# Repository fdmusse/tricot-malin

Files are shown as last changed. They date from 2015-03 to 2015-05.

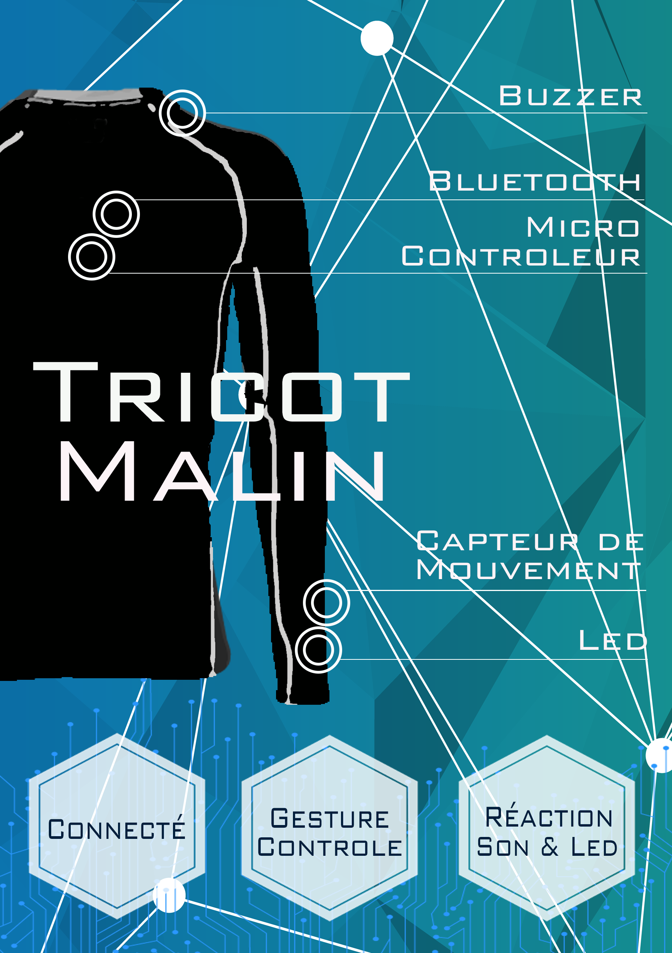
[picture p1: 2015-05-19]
img/flyerPoster/Poster.png

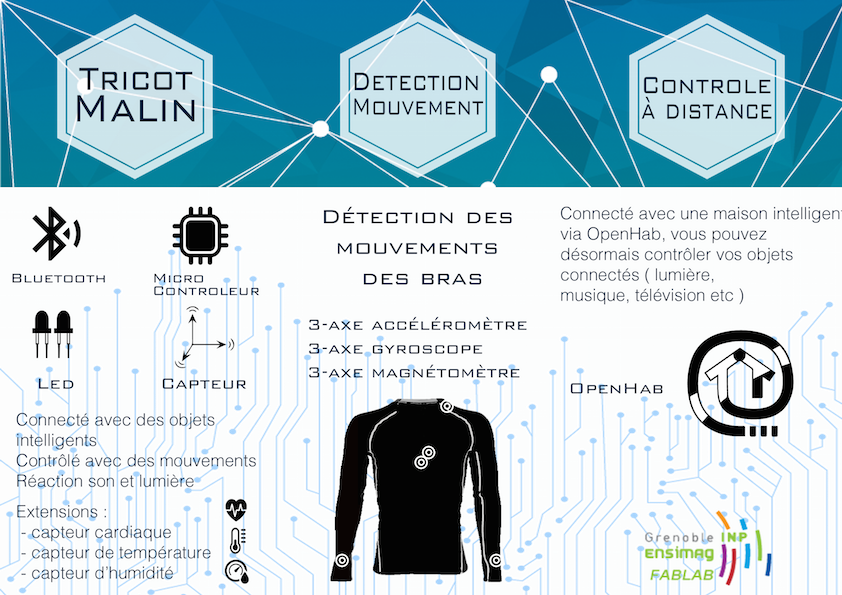
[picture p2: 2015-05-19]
img/flyerPoster/Flyer.png

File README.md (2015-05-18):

# tricot-malin

Tricot Malin (smart sweater in French) is a smart t-shirt that makes it possible to interact with the digital environment that surround us through the use of simple gestures.

## Materials

* *1 [JeeNode v6](http://jeelabs.net/projects/hardware/wiki/JeeNode):* microcontroller running at 3.3V
* *2 [Sparkfun LSM9DS0 breakout board](https://www.sparkfun.com/products/12636):* inertial measurement units, one for each arm
* *2 [RedBearLab BLE Mini](http://redbearlab.com/blemini/):* Bluetooth modules
* *2 RGB LED strips of [AdaFruit NeoPixel](http://www.adafruit.com/product/1460):* luminous feedback, one for each arm
* *1 buzzer:* sonorous feedback
* *Jumper wires (a lot!)*: to connect everything together
* *FTDI USB to serial board:* to upload code to the JeeNode

## Requirements

  * [Python 2.7](https://www.python.org/downloads/)
  * [Arduino IDE](http://www.arduino.cc/en/Main/Software)
  * [Sparkun LSM9DS0 Arduino Library](https://github.com/sparkfun/SparkFun_LSM9DS0_Arduino_Library)
  * [Adafruit NeoPixel Arduino Library](https://github.com/adafruit/Adafruit_NeoPixel)
  * [BLE Mini HCI Library](https://github.com/RedBearLab/BLE_HCI)

## Instructions

1. Upload the [HCI UART slave firmware](https://github.com/RedBearLab/BLE_HCI/blob/master/cc2540_hci_fw/HCI_UART_115200bps_20130429.bin.zip) to the BLE Mini which will be connected to the JeeNode.
2. Connect the components to the JeeNode according to the [schematic](https://github.com/fdmusse/tricot-malin/blob/master/schematic/tricot-malin-schematic.png) using the jumper wires.
3. Upload the code `arduino/orientation_to_bluetooth/orientation_to_bluetooth.ino` to the JeeNode:
 * Connect the JeeNode to your computer with a FTDI USB to serial board, such as the [USB BUB II](http://moderndevice.com/product/usb-bub-ii/). 
  * Open the code in the Arduino IDE.
  * Select `Arduino Uno` as board and the appropriate serial port.
  * Disconnect BLE Mini from `TX` and `RX` pins.
  * Press upload.
  * Reconnect BLE Mini to `TX` and `RX` pins.

4. Connect the BLE Mini containing the [HCI central firmware](https://github.com/RedBearLab/BLE_HCI/blob/master/cc2540_hci_fw/HCI_USBCDC_115200_20130429.bin.zip) to your computer with a Micro USB cable. 
5. Set the global variable `TX.Port` in `bluetooth/bluetooth_central.py` to the approriate port to which the BLE Mini is connected.
6. Run the Python code `bluetooth_central.py`:
  * Press `n` to enable notifications and then `d` to search for BLE modules nearby.
  * After the discovery, press `e` to establish the connection to the BLE module connected to the JeeNode.
  * When the connection is successful, press `n` again to start the communication.
  * To end the execution, press `q` and then close any visualization window.

##  Usage

* Turning an arm by 180° will trigger the corresponding action.
* When a gesture is detected, the LEDs of the arm will shortly turn on.
* When the lights turn off, a new gesture is ready to be detected. 
* The gesture of each arm has its own an independent associated action.

## Documentation

All the project's documentation is available at our [Wiki](https://github.com/fdmusse/tricot-malin/wiki).

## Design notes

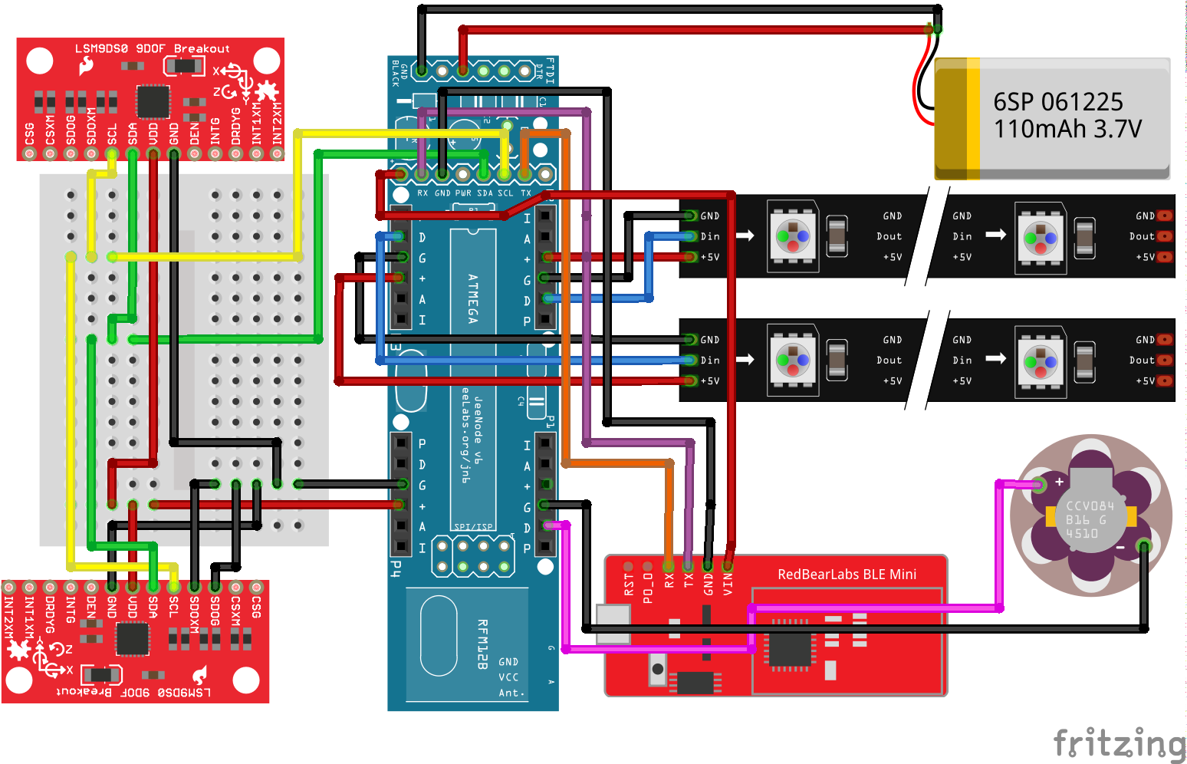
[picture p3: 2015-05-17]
schematic/tricot-malin-schematic.png

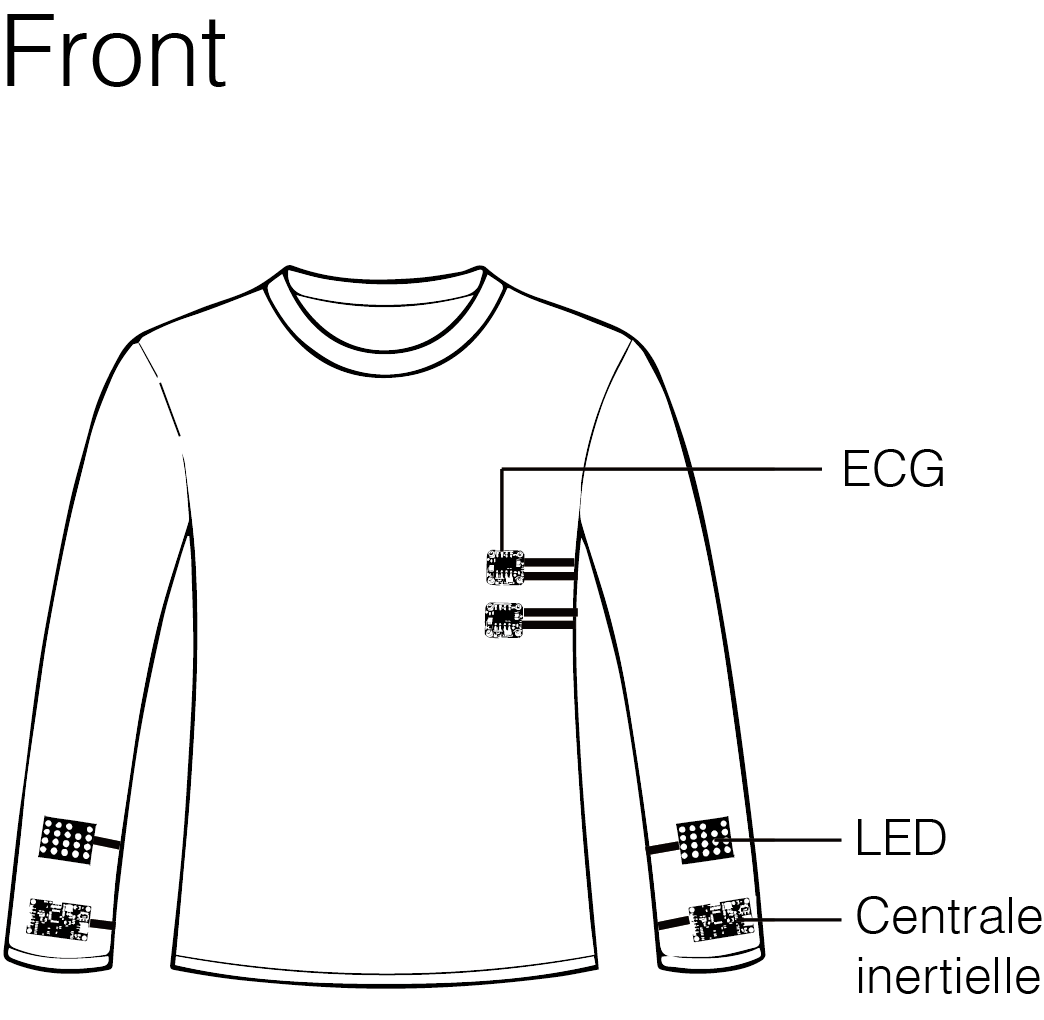
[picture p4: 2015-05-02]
img/diagram/t-shirt_front.png

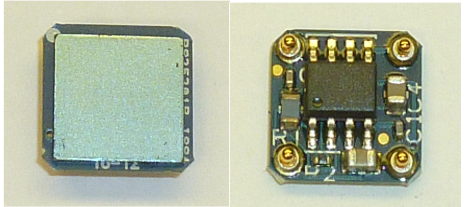
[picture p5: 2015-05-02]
img/ecg/ecgSensor.png

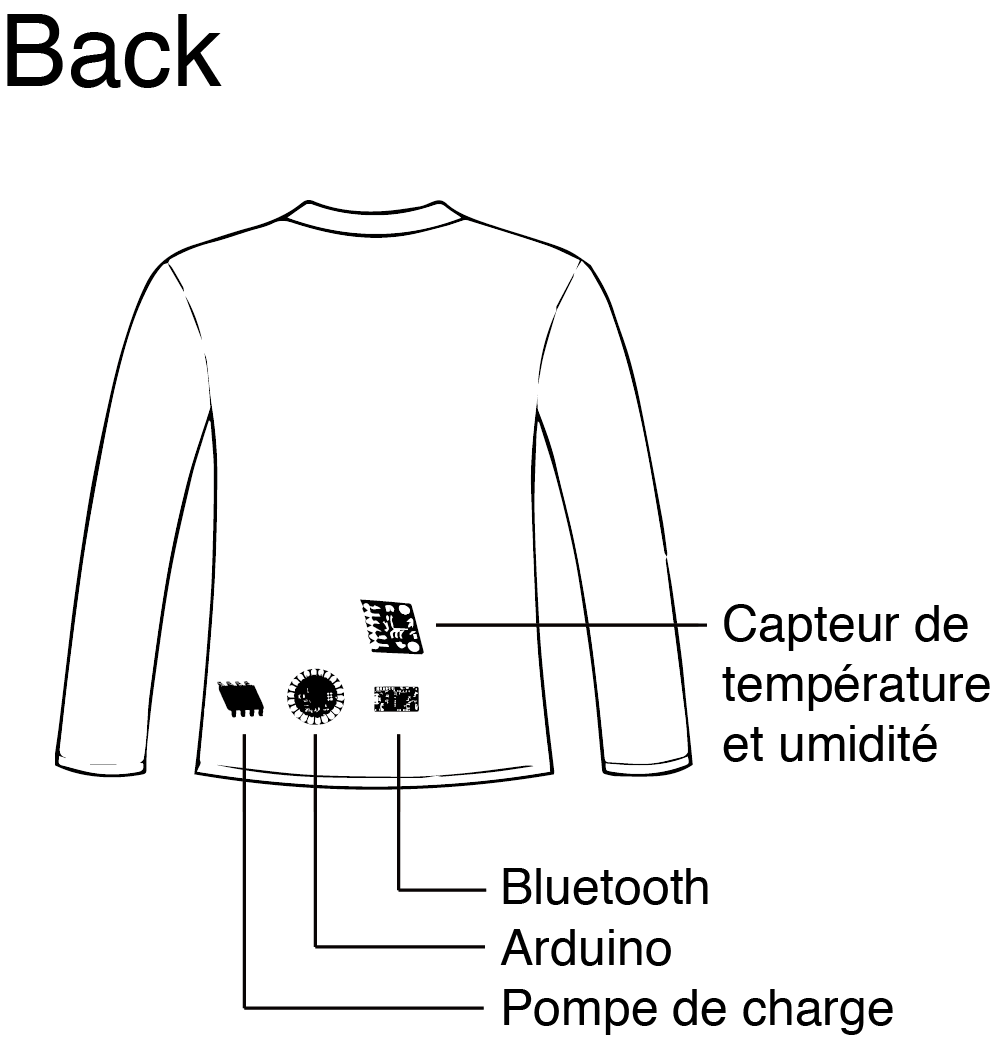
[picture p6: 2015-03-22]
img/diagram/t-shirt_back2.png

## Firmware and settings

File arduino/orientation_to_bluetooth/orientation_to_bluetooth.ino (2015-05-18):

/*
Tricot Malin

This code was heavily inspired by:
 
 - AHRS example from Sparkfun's LSM9DS0 library (https://github.com/sparkfun/
 LSM9DS0_Breakout/blob/master/Libraries/Arduino/examples/SparkFun_LSM9DS0_AHRS/
 SparkFun_LSM9DS0_AHRS.ino)
 
 - BiscuitPeripheral example from RedBearLab's BLE HCI library (https://github.
 com/RedBearLab/BLE_HCI/blob/master/arduino/libraries/BLEHCI/examples/Biscuit
 Peripheral/BiscuitPeripheral.ino)

LSM9DS0 being used in I2C mode.
*/

#include <SPI.h> /* Included for SFE_LSM9DS0 library, which requires both the 
SPI and Wire libraries even though we are only using I2C */
#include <Wire.h>
#include <SFE_LSM9DS0.h>
#include "data_fusion.h"
#include <Adafruit_NeoPixel.h>

#define OK 0x49D4

#define RIGHT_LSM9DS0_XM  0x1D // Would be 0x1E if SDO_XM is LOW 
#define RIGHT_LSM9DS0_G   0x6B  // Would be 0x6A if SDO_G is LOW
#define LEFT_LSM9DS0_XM  0x1E
#define LEFT_LSM9DS0_G   0x6A

#define RIGHT_LEDS_PIN 5 // D of P2 JeeNode
#define LEFT_LEDS_PIN 6 // D of P3 JeeNode

#define BUZZER_PIN 7
#define BUZZER_GROUND_PIN 3
#define BUZZER_NOTE 440
#define BUZZER_TIME 2000 // 2 seconds

LSM9DS0 right_imu(MODE_I2C, RIGHT_LSM9DS0_G, RIGHT_LSM9DS0_XM);
LSM9DS0 left_imu(MODE_I2C, LEFT_LSM9DS0_G, LEFT_LSM9DS0_XM);

imu_data right_data, left_data;

float declination = 1.37; // declination at Saint Martin D'Hères, France is 1°22' E ± 0°20' on 16/05/2015

Adafruit_NeoPixel right_leds = Adafruit_NeoPixel(3, RIGHT_LEDS_PIN, NEO_GRB + NEO_KHZ800);
Adafruit_NeoPixel left_leds = Adafruit_NeoPixel(3, LEFT_LEDS_PIN, NEO_GRB + NEO_KHZ800);

void setup()
{
    Serial.begin(115200); // Start serial at 115200 bps
            
    // begin() returns a 16-bit value which includes both the gyro 
    // and accelerometers WHO_AM_I response. Check this to
    // make sure communication was successful.
    right_data.status = right_imu.begin();

    if (right_data.status != OK)
        Serial.println("Error connecting to right LSM9DS0");

    left_data.status = left_imu.begin();

    if (left_data.status != OK)
        Serial.println("Error connecting to left LSM9DS0");
        
    imu_setup(&right_imu, &right_data);
    imu_setup(&left_imu, &left_data);
    
    right_leds.begin();
    left_leds.begin();

    for(uint16_t i = 0; i < right_leds.numPixels(); i++) {
      right_leds.setPixelColor(i, 0, 0, 0);
  }

      for(uint16_t i = 0; i < left_leds.numPixels(); i++) {
      left_leds.setPixelColor(i, 0, 0, 0);
  }
    
    right_leds.show();
    left_leds.show();

    pinMode(BUZZER_GROUND_PIN, OUTPUT);
    digitalWrite(BUZZER_GROUND_PIN, LOW);

    //pinMode(BUZZER_PIN, OUTPUT);
}

void loop()
{
    if (Serial.available())
    {
        char readByte = Serial.read();
        if (readByte == 'r')
        {
            tone(BUZZER_PIN, BUZZER_NOTE, BUZZER_TIME);
            colorWipe(&right_leds, right_leds.Color(0, 255, 0));
            noTone(BUZZER_PIN);
        }
        else if (readByte == 'l')
        {
            tone(BUZZER_PIN, BUZZER_NOTE, BUZZER_TIME);
            colorWipe(&left_leds, left_leds.Color(0, 255, 0));
            noTone(BUZZER_PIN);
        }
        else
            Serial.println("Invalid byte received.");
    }

    // right arm imu_read
    if (right_data.status == OK)
    {
        imu_read(&right_imu, &right_data);
        MadgwickQuaternionUpdate(&right_data);
        quaternions_to_tait_bryan(&right_data);    
        Serial.print("r,"); // right
        imu_send(&right_data);
    }

    // left arm IMU
    if (left_data.status == OK)
    {
        imu_read(&left_imu, &left_data);
        MadgwickQuaternionUpdate(&left_data);
        quaternions_to_tait_bryan(&left_data);
        Serial.print("l,"); // left
        imu_send(&left_data);
    }
    
    delay(25); // updates at ~40 Hz (1/40 = 25 ms)
}

// Fill the dots one after the other with a color
void colorWipe(Adafruit_NeoPixel *strip, uint32_t c) {
  

  for(uint16_t i = 0; i < strip->numPixels(); i++) {
      strip->setPixelColor(i, c);
      strip->show();
      delay(666);
  }

  delay(1000);

  for(int16_t i = strip->numPixels() - 1; i >= 0; i--) {
      delay(666);
      strip->setPixelColor(i, 0, 0, 0); // turns off
      strip->show();
    }
}

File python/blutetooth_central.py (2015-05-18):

from select import select
import serial
import os, sys
import struct
from imu_visualization import *
from detect_gestures import *
import string
import time

# not posix system, we need msvcrt library for kbhit
# for posix, we need termios and atexit
if os.name <> 'posix':
  import msvcrt
else:
  import atexit
  import termios

#
#    Structures
#

class KB:
  
    def __init__(self):
        '''Creates a KBHit object that you can call to do various keyboard things.
        '''

        if os.name == 'nt':
            pass
            
        else:
            
            # Save the terminal settings
            self.fd = sys.stdin.fileno()
            self.new_term = termios.tcgetattr(self.fd)
            self.old_term = termios.tcgetattr(self.fd)
            
            # New terminal setting unbuffered
            self.new_term[3] = (self.new_term[3] & ~termios.ICANON & ~termios.ECHO)
            termios.tcsetattr(self.fd, termios.TCSAFLUSH, self.new_term)
            
            # Support normal-terminal reset at exit
            atexit.register(self.set_normal_term)
            
            
    def set_normal_term(self):
        ''' Resets to normal terminal.  On Windows this is a no-op.
        '''
        
        if os.name == 'nt':
            pass
            
        else:
            termios.tcsetattr(self.fd, termios.TCSAFLUSH, self.old_term)


    def getch(self):
        ''' Returns a keyboard character after kbhit() has been called.
        Should not be called in the same program as getarrow().
        '''
        
        s = ''
        
        if os.name == 'nt':
            return msvcrt.getch().decode('utf-8')
            
        else:
            return sys.stdin.read(1)
                    

    def getarrow(self):
        ''' Returns an arrow-key code after kbhit() has been called. Codes are
        0 : up
        1 : right
        2 : down
        3 : left
        Should not be called in the same program as getch().
        '''
        
        if os.name == 'nt':
            msvcrt.getch() # skip 0xE0
            c = msvcrt.getch()
            vals = [72, 77, 80, 75]
    
        else:
            c = sys.stdin.read(3)[2]
            vals = [65, 67, 66, 68]
    
        return vals.index(ord(c.decode('utf-8')))
    

    def kbhit(self):
        ''' Returns True if keyboard character was hit, False otherwise.
        '''
        if os.name == 'nt':
            return msvcrt.kbhit()
            
        else:
            dr,dw,de = select([sys.stdin], [], [], 0)
            return dr != []

class gapDevDiscReq_t:
    taskID           = None
    mode             = None
    activeScan       = None
    whiteList        = None

class gapEstLinkReq_t:
    taskID           = None
    highDutyCycle    = None    
    whiteList        = None
    addrTypePeer     = None    
    peerAddr         = None

class attWriteReq_t:
    handle           = None              # Handle of the attribute to be written (must be first field)
    len              = None              # Length of value
    value            = None              # Value of the attribute to be written
    sig              = None              # Authentication Signature status (not included (0), valid (1), invalid (2))
    cmd              = None              # Command Flag

#
#    Constants
#

GAP_PROFILE_CENTRAL           = '\x08'

DEVDISC_MODE_NONDISCOVERABLE  = '\x00'
DEVDISC_MODE_GENERAL          = '\x01'
DEVDISC_MODE_LIMITED          = '\x02'
DEVDISC_MODE_ALL              = '\x03'

# Discovey mode (limited, general, all)
DEFAULT_DISCOVERY_MODE        = DEVDISC_MODE_ALL

# TRUE to use active scan
DEFAULT_DISCOVERY_ACTIVE_SCAN = '\x01' # True

# TRUE to use white list during discovery
DEFAULT_DISCOVERY_WHITE_LIST  = '\x00' # False

# TRUE to use high scan duty cycle when creating link
DEFAULT_LINK_HIGH_DUTY_CYCLE  = '\x00' # False

# TRUE to use white list when creating link
DEFAULT_LINK_WHITE_LIST       = '\x00' # False

#
#    Global
#

# our transport layer will be serial port
TX = serial.Serial()

# store the address found
found_address = None

#
is_connected = False

#
#    Defines the BLE GAP command APIs
#

def GAP_DeviceInit( taskID, profileRole, maxScanResponses, irk, srk, signCounter ):
    buf = ''

    buf += '\x01'                       # -Type    : 0x01 (Command)
    buf += '\x00'                 # -Opcode  : 0xFE00 (GAP_DeviceInit)
    buf +=  '\xFE'

    buf += '\x26'                 # -Data Length
    buf += profileRole            #  Profile Role
    buf += maxScanResponses       #  MaxScanRsps
    buf += irk                    #
    buf += srk                    #
    buf += signCounter            #

    TX.write(buf)

    # ToDo: here should wait for command status
    return True

def GAP_DeviceDiscoveryRequest( params ):    
    buf = ''

    buf += '\x01'                       # -Type    : 0x01 (Command)
    buf += '\x04'                 # -Opcode  : 0xFE04 (GAP_DeviceDiscoveryRequest)
    buf += '\xFE'

    buf += '\x03'                 # -Data Length
    buf += params.mode            #  Mode
    buf += params.activeScan      #  ActiveScan
    buf += params.whiteList       #  WhiteList

    TX.write(buf)

    # ToDo: here should wait for command status
    return True

def GAP_EstablishLinkReq( params ):
    buf = ''

    buf += '\x01'
    buf += '\x09\xFE'

    buf += struct.pack('B', 3 + 6)  # 6 is B_ADDR_LEN

    buf += params.highDutyCycle
    buf += params.whiteList  
    buf += params.addrTypePeer

    buf += params.peerAddr

    TX.write(buf)

    # ToDo: here should wait for command status
    return True;

#
#    Defines the BLE GATT command APIs
#

def GATT_WriteCharValue( connHandle, req, taskId ): 
    buf = ''

    buf += '\x01'
    buf += '\x92\xFD'

    buf += struct.pack('B', 4 + ord(req.len))

    buf += connHandle
    buf += req.handle
    buf += req.value
  
    TX.write(buf)

    # ToDo: here should wait for command status
    return True

#
#    Defines the BLE GAP Central Role APIs
#

gapCentralRoleTaskId      = '\x00'
gapCentralRoleIRK         = struct.pack('16s', '\x00')
gapCentralRoleSRK         = struct.pack('16s', '\x00')
gapCentralRoleSignCounter = '\x01'
gapCentralRoleMaxScanRes  = '\x05'

def GAPCentralRole_StartDevice():
    return GAP_DeviceInit( gapCentralRoleTaskId, GAP_PROFILE_CENTRAL,
    gapCentralRoleMaxScanRes, gapCentralRoleIRK,
    gapCentralRoleSRK, gapCentralRoleSignCounter )

def GAPCentralRole_EstablishLink( highDutyCycle, whiteList, addrTypePeer, peerAddr ):
    params = gapEstLinkReq_t

    params.taskID        = gapCentralRoleTaskId
    params.highDutyCycle = highDutyCycle
    params.whiteList     = whiteList
    params.addrTypePeer  = addrTypePeer
    params.peerAddr      = peerAddr

    return GAP_EstablishLinkReq( params )
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

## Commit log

2015-05-02 code imu cube
2015-05-15 Added data fusion for a single IMU.
2015-05-15 Updated IMU visualization.
2015-05-15 Corrected error in comment.
    [orientation_to_bluetooth.ino]
2015-05-15 Removed interruptions from Arduino program.
2015-05-16 Modified code to deal with data from both IMUs.
2015-05-16 Added LED output.
2015-05-16 Added updated IMU visualization, now in Python.
2015-05-16 Linked IMU visualization to data received by Bluetooth.
2015-05-17 Added materials, requirements and instructions to the readme file.
2015-05-17 Added schematic.
    [tricot-malin-schematic.fzz]
2015-05-17 Added schematic link to readme file.
